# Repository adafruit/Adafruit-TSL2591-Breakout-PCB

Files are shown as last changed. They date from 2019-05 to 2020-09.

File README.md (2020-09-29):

## Adafruit TSL2591 Breakout PCB
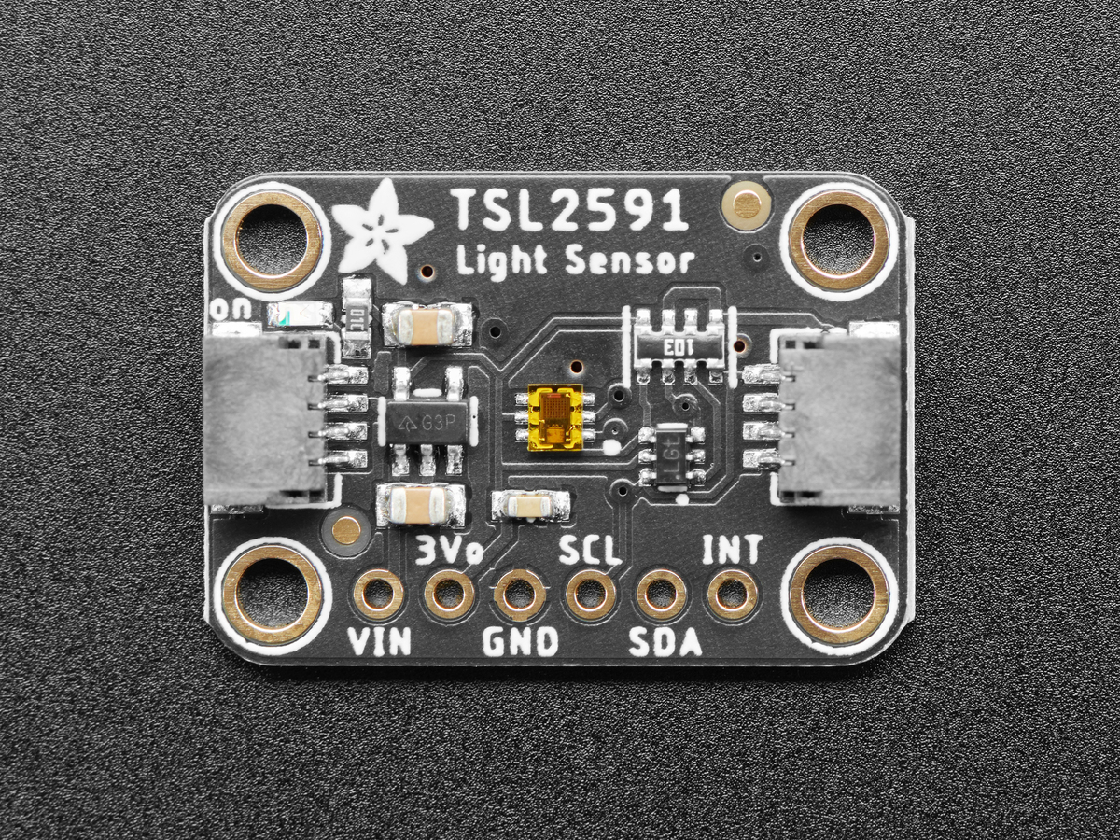
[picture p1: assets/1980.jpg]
<a href="http://www.adafruit.com/products/1980"><br/>
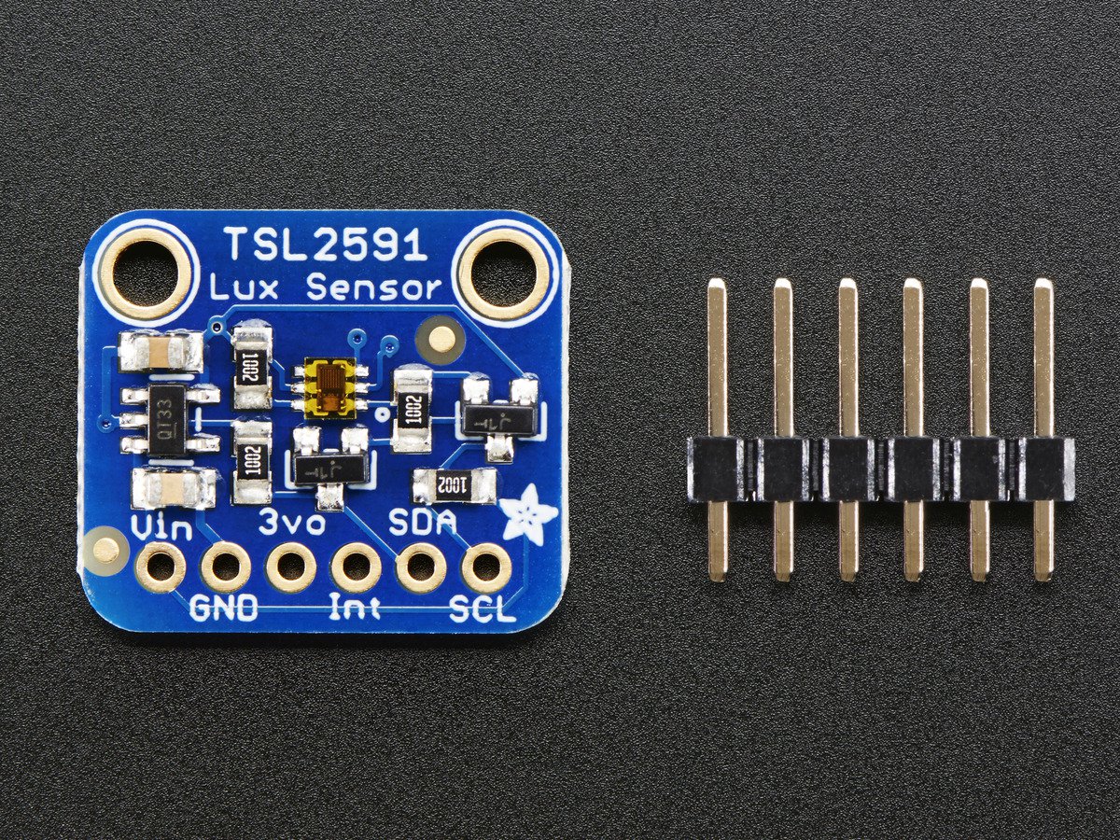
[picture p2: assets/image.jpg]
<a href="http://www.adafruit.com/products/1980"><br/>
Click here to purchase one from the Adafruit shop</a>

When the future is dazzlingly-bright, this ultra-high-range luminosity sensor will help you measure it. The TSL2591 luminosity sensor is an advanced digital light sensor, ideal for use in a wide range of light situations. Compared to low cost CdS cells, this sensor is more precise, allowing for exact lux calculations and can be configured for different gain/timing ranges to detect light ranges from 188 uLux up to 88,000 Lux on the fly.

The best part of this sensor is that it contains both infrared and full spectrum diodes! That means you can separately measure infrared, full-spectrum or human-visible light. Most sensors can only detect one or the other, which does not accurately represent what human eyes see (since we cannot perceive the IR light that is detected by most photo diodes) This sensor is much like the TSL2561 but with a wider range (and the interface code is different). This sensor has a massive 600,000,000:1 dynamic range! Unlike the TSL2561 you cannot change the I2C address, so keep that in mind.

The built in ADC means you can use this with any microcontroller, even if it doesn't have analog inputs. The current draw is extremely low, so its great for low power data-logging systems. about 0.4mA when actively sensing, and less than 5 uA when in power-down mode.

PCB files for the Adafruit TSL2591 Breakout PCB. The format is EagleCAD schematic and board layout
- https://www.adafruit.com/product/1980

### License

Adafruit invests time and resources providing this open source design, please support Adafruit and open-source hardware by purchasing products from [Adafruit](https://www.adafruit.com)!

All text above must be included in any redistribution

Designed by Limor Fried/Ladyada for Adafruit Industries.
Creative Commons Attribution/Share-Alike, all text above must be included in any redistribution. 
See license.txt for additional information.

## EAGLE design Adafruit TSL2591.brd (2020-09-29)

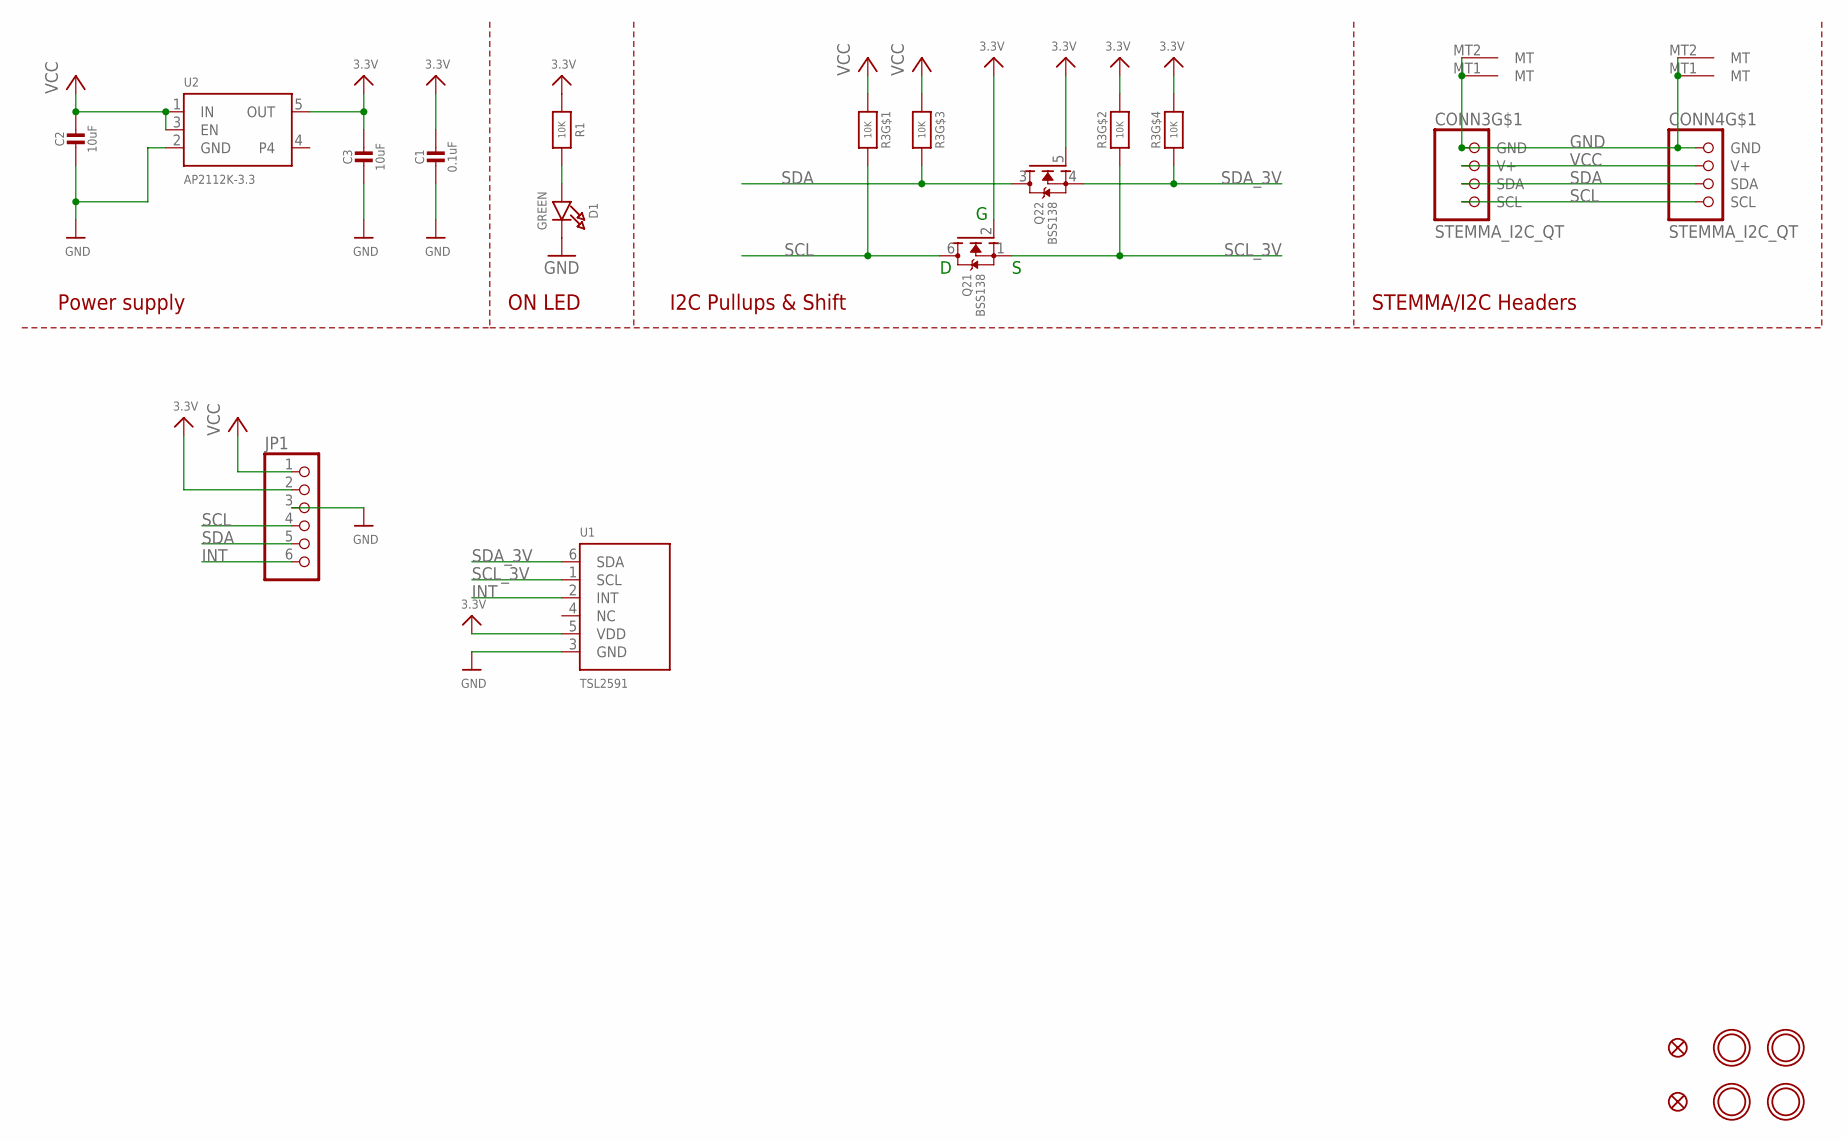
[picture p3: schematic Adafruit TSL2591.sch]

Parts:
C1: 0.1uF; 0603-NO
C2, C3: 10uF; 0805-NO
CONN3, CONN4: STEMMA_I2C_QT; JST_SH4
D1: GREEN; CHIPLED_0603_NOOUTLINE
FID3, FID4: FIDUCIAL_1MM
JP1: HEADER-1X670MIL; 1X06_ROUND_70
Q2: BSS138; SOT363
R1: 10K; 0603-NO
R3: 10K; RESPACK_4X0603
U1: TSL2591; DFN6_TAOS
U2: AP2112K-3.3; SOT23-5
U$1, U$17, U$19, U$21: MOUNTINGHOLE2.5; MOUNTINGHOLE_2.5_PLATED

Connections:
3.3V: C1.1, C3.1, JP1.2, Q2.2 (G), Q2.5 (G), R1.1, R3.2 (1), R3.4 (1), U1.5 (VDD), U2.5 (OUT)
GND: C1.2, C2.2, C3.2, CONN3.1 (GND), CONN3.MT1 (MT), CONN3.MT2 (MT), CONN4.1 (GND), CONN4.MT1 (MT), CONN4.MT2 (MT), D1.C, JP1.3, U1.3 (GND), U2.2 (GND)
INT: JP1.6, U1.2 (INT)
unnamed: D1.A, R1.2
SCL: CONN3.4 (SCL), CONN4.4 (SCL), JP1.4, Q2.6 (D), R3.8 (2)
SCL_3V: Q2.1 (S), R3.7 (2), U1.1 (SCL)
SDA: CONN3.3 (SDA), CONN4.3 (SDA), JP1.5, Q2.3 (D), R3.6 (2)
SDA_3V: Q2.4 (S), R3.5 (2), U1.6 (SDA)
VCC: C2.1, CONN3.2 (V+), CONN4.2 (V+), JP1.1, R3.1, R3.3 (1), U2.1 (IN), U2.3 (EN)

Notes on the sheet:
I2C Pullups & Shift
STEMMA/I2C Headers
ON LED
Power supply

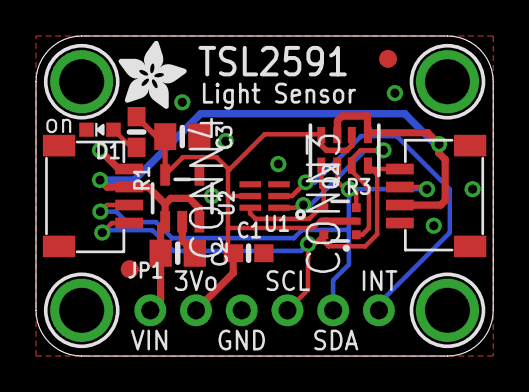
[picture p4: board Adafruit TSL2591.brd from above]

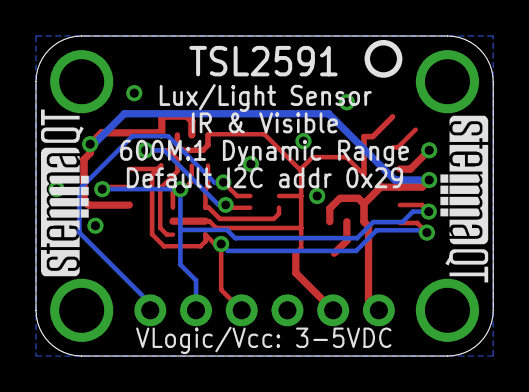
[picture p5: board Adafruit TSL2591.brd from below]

Board: 2 copper layers, 25.4 x 17.8 mm, 22 parts (3 on the bottom side), 9 nets.

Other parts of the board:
U$22: ADAFRUIT_3.5MM
U$25: PCBFEAT-REV-040
U$30, U$31: STEMMAQT

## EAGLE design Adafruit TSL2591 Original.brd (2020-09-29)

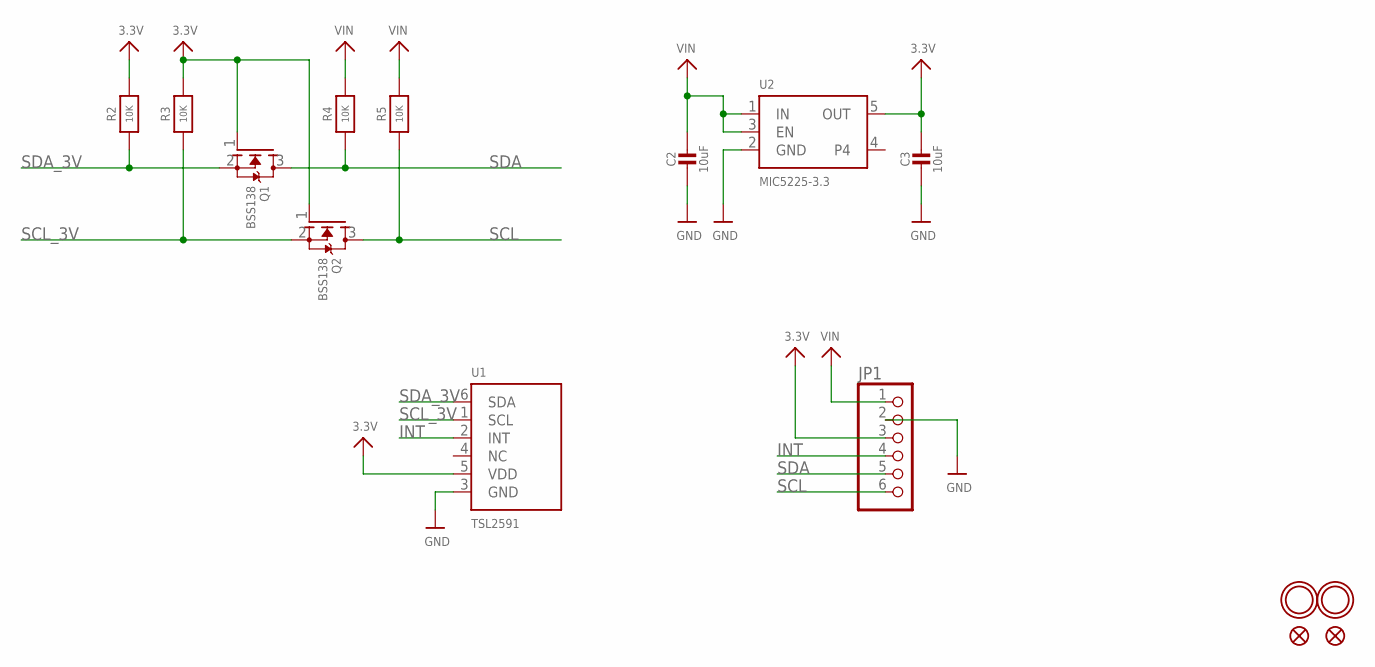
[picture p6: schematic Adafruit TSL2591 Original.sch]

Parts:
C2, C3: 10uF; 0805-NO
FID1, FID2: FIDUCIAL""; FIDUCIAL_1MM
JP1: HEADER-1X676MIL_FULLROUND; 1X06_ROUND_FULL_76
Q1, Q2: BSS138; SOT23-WIDE
R2, R3, R4: 10K; 0805-NO
R5: 10K; _0805MP
U1: TSL2591; DFN6_TAOS
U2: MIC5225-3.3; SOT23-5
U$18, U$19: MOUNTINGHOLE2.5; MOUNTINGHOLE_2.5_PLATED

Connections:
3.3V: C3.1, JP1.3, Q1.1 (G), Q2.1 (G), R2.2, R3.2, U1.5 (VDD), U2.5 (OUT)
GND: C2.2, C3.2, JP1.2, U1.3 (GND), U2.2 (GND)
INT: JP1.4, U1.2 (INT)
SCL: JP1.6, Q2.3 (D), R5.1
SCL_3V: Q2.2 (S), R3.1, U1.1 (SCL)
SDA: JP1.5, Q1.3 (D), R4.1
SDA_3V: Q1.2 (S), R2.1, U1.6 (SDA)
VIN: C2.1, JP1.1, R4.2, R5.2, U2.1 (IN), U2.3 (EN)

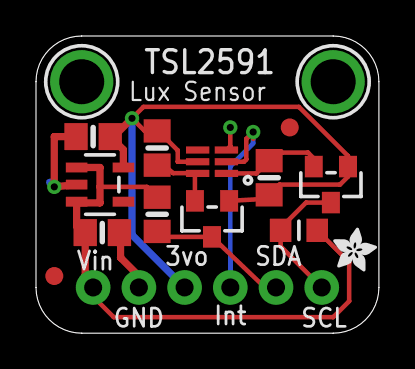
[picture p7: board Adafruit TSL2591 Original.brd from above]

Board: 2 copper layers, 19.1 x 16.5 mm, 17 parts (1 on the bottom side), 8 nets.

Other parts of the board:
U$15: ADAFRUIT_2.5MM
U$20: ADAFRUIT_5MM

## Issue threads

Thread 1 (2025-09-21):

Possible to export STEP file of this board?

dfcs, 2025-09-21:
Hello, I have downloaded the SCH and BRD files from this repo and opened them in KiCAD. I can't seem to export a STEP file that includes the board components and I don't see this board in the main Adafruit CAD repo. If you could do a quick export, that would be amazing! Thanks.

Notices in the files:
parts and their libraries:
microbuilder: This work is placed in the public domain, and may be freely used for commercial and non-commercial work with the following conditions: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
